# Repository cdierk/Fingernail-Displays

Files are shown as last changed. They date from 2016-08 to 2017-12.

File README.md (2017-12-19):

# Fingernail-Displays

## Hardware notes
The pink board is a [Teensy 3.2](https://www.pjrc.com/teensy/index.html). Here's the [pinout.](https://www.pjrc.com/teensy/pinout.html)

The tiny red epaper breakout board is from [this hackaday project.](https://hackaday.io/project/13327-teensy-e-paper-adapter-board).

## Software notes
The [code for the red e-paper breakout board is here,](https://github.com/jarek319/EPD215). Note that it was designed w/ an older pin layout, so you need to swap two of the pins as per [this issue on github.](https://github.com/jarek319/EPD215/issues/4).
Specifically, 

### Annotations
Difference between SPI and SWSPI is d1 and d0 are set to output in SWSPI.

Power on the cog driver:
```
initScreen()
...
  digitalWrite( _rs, HIGH );        //RES# = 1    <-----
  delay( 1 );                       //Delay 1ms          \
  digitalWrite( _cs, HIGH );        //CS# = 1      <---- these two lines power on the cog driver.

  Serial.println( "Waiting for busy signal" );
  while ( digitalRead( _bs ) == HIGH ); //Make sure BUSY = LOW      <---- first step of initializing COG driver.
```
[source](https://github.com/jarek319/EPD215/blob/e8205ba3651f23074bca707f821be8e2f3143674/EPD215.cpp#L281)
[download datasheet, pg. 10 of datasheet](http://www.pervasivedisplays.com/LiteratureRetrieve.aspx?ID=232068)

#### Testing
pin setup (SPI)
EPD215(17, 16, 14, 15)
Output: https://www.dropbox.com/s/jrkega85on69x7t/Screenshot%202017-12-15%2012.04.25.png?dl=0

EPD215(17, 16, 15, 14)

## Code to upload bitmap images

0. If you're using [this adapter board and a Teensy, as here,](https://hackaday.io/project/13327-teensy-e-paper-adapter-board) follow these steps.
1. Download [EPD215 library from here.](https://github.com/jarek319/EPD215). Those instructions will also have you install the [Adafruit GFX library.](https://github.com/adafruit/Adafruit-GFX-Library)
2.

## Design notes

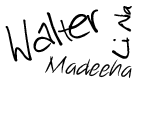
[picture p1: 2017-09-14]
Eink Designs/signatures3_1_9.png

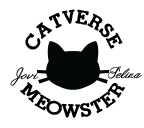
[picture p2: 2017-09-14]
Eink Designs/catverse_1_9.png

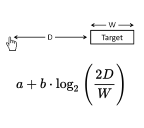
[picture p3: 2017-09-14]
Eink Designs/fitts_1_9.png

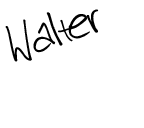
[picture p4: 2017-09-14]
Eink Designs/signatures1_1_9.png

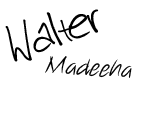
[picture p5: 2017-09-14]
Eink Designs/signatures2_1_9.png

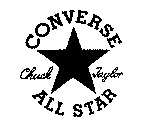
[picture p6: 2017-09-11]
Eink Designs/converse_1_9.jpg

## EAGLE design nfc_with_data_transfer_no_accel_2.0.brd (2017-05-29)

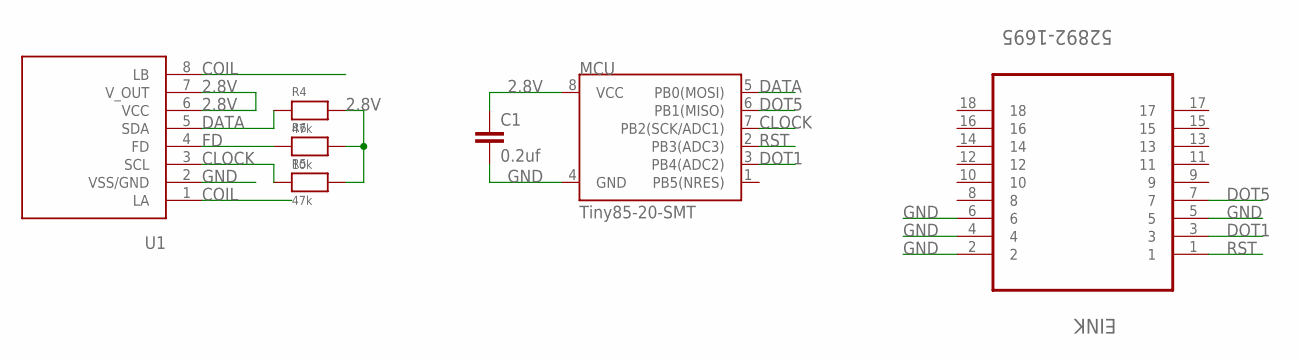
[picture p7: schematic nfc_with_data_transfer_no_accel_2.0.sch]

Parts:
C1: 0.2uf; 1206
EINK: 52892-1695; MOLEX_52892-1695
MCU: Tiny85-20-SMT; SO08-EIAJ
R4, R5: 47k; 0603
R6: 10k; 0603
U1: NT3H1101

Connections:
2.8V: C1.1, MCU.8 (VCC), R4.2, R5.2, R6.2, U1.6 (VCC), U1.7 (V_OUT)
CLOCK: MCU.7 (PB2(SCK/ADC1)), R5.1, U1.3 (SCL)
COIL: U1.1 (LA), U1.8 (LB)
DATA: MCU.5 (PB0(MOSI)), R4.1, U1.5 (SDA)
DOT1: EINK.3, MCU.3 (PB4(ADC2))
DOT5: EINK.7, MCU.6 (PB1(MISO))
FD: R6.1, U1.4 (FD)
GND: C1.2, EINK.2, EINK.4, EINK.5, EINK.6, MCU.4 (GND), U1.2 (VSS/GND)
RST: EINK.1, MCU.2 (PB3(ADC3))

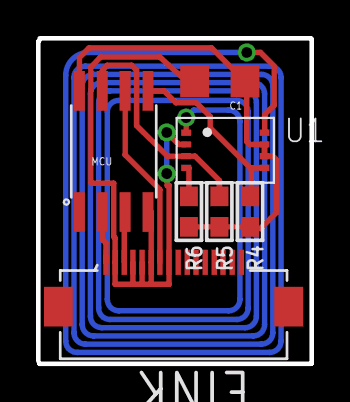
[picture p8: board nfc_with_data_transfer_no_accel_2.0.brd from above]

Board: 2 copper layers, 15.2 x 18.1 mm, 7 parts (0 on the bottom side), 9 nets.

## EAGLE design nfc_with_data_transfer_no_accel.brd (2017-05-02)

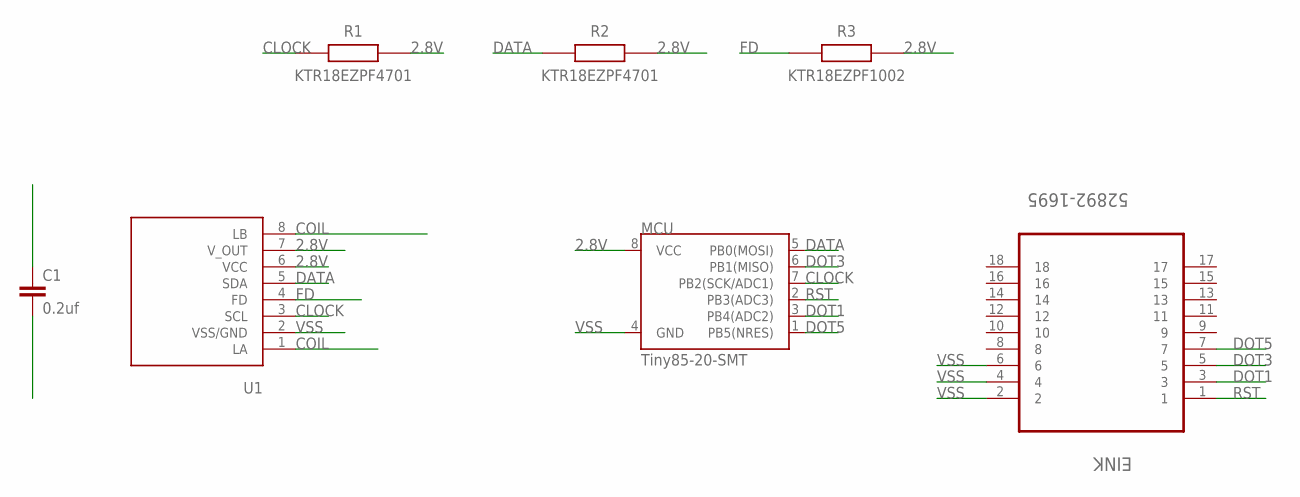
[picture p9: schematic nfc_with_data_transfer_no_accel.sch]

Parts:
C1: 0.2uf; 1206
EINK: 52892-1695; MOLEX_52892-1695
MCU: Tiny85-20-SMT; SO08-EIAJ
R1, R2: KTR18EZPF4701; RESC3216X65N
R3: KTR18EZPF1002; RESC3216X65N
U1: NT3H1101

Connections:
2.8V: C1.1, MCU.8 (VCC), R1.2, R2.2, R3.2, U1.6 (VCC), U1.7 (V_OUT)
CLOCK: MCU.7 (PB2(SCK/ADC1)), R1.1, U1.3 (SCL)
COIL: U1.1 (LA), U1.8 (LB)
DATA: MCU.5 (PB0(MOSI)), R2.1, U1.5 (SDA)
DOT1: EINK.3, MCU.3 (PB4(ADC2))
DOT3: EINK.5, MCU.6 (PB1(MISO))
DOT5: EINK.7
FD: R3.1, U1.4 (FD)
RST: EINK.1, MCU.2 (PB3(ADC3))
VSS: C1.2, EINK.2, EINK.4, EINK.6, MCU.4 (GND), U1.2 (VSS/GND)

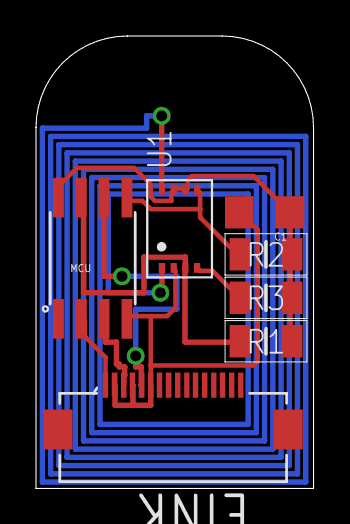
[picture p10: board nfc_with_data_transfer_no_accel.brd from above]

Board: 2 copper layers, 15.4 x 25.1 mm, 7 parts (0 on the bottom side), 9 nets.

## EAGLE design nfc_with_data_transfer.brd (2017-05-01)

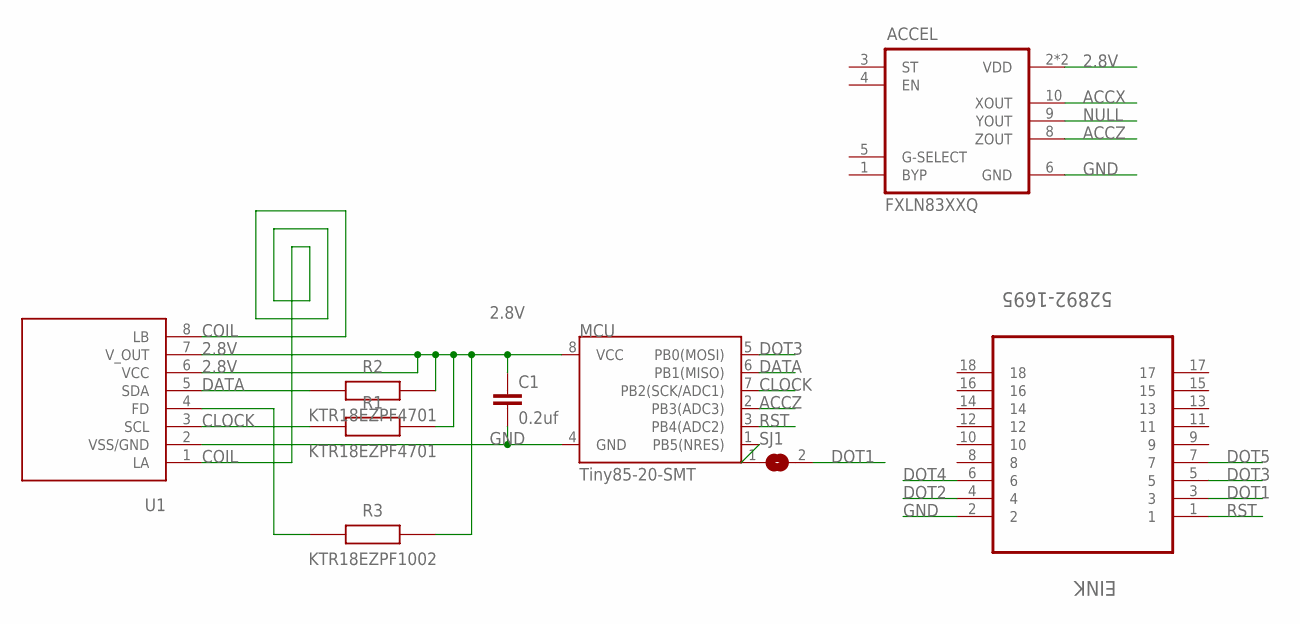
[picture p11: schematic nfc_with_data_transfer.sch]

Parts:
ACCEL: FXLN83XXQ; QFN12-3X3
C1: 0.2uf; 1206
EINK: 52892-1695; MOLEX_52892-1695
MCU: Tiny85-20-SMT; SO08-EIAJ
R1, R2: KTR18EZPF4701; RESC3216X65N
R3: KTR18EZPF1002; RESC3216X65N
SJ1: SOLDERJUMPER; SOLDERJUMPER_ARROW_NOPASTE
U1: NT3H1101

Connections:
2.8V: ACCEL.2 (VDD), ACCEL.7 (VDD), C1.1, MCU.8 (VCC), R1.2, R2.2, R3.2, U1.6 (VCC), U1.7 (V_OUT)
ACCX: ACCEL.10 (XOUT)
ACCZ: ACCEL.8 (ZOUT), MCU.2 (PB3(ADC3))
CLOCK: MCU.7 (PB2(SCK/ADC1)), U1.3 (SCL)
COIL: U1.1 (LA), U1.8 (LB)
DATA: MCU.6 (PB1(MISO)), U1.5 (SDA)
DOT1: EINK.3, SJ1.2
DOT2: EINK.4
DOT3: EINK.5, MCU.5 (PB0(MOSI))
DOT4: EINK.6
DOT5: EINK.7
GND: ACCEL.6 (GND), C1.2, EINK.2, MCU.4 (GND), U1.2 (VSS/GND)
unnamed: MCU.1 (PB5(NRES)), SJ1.1
unnamed: R3.1, U1.4 (FD)
NULL: ACCEL.9 (YOUT)
RST: EINK.1, MCU.3 (PB4(ADC2))

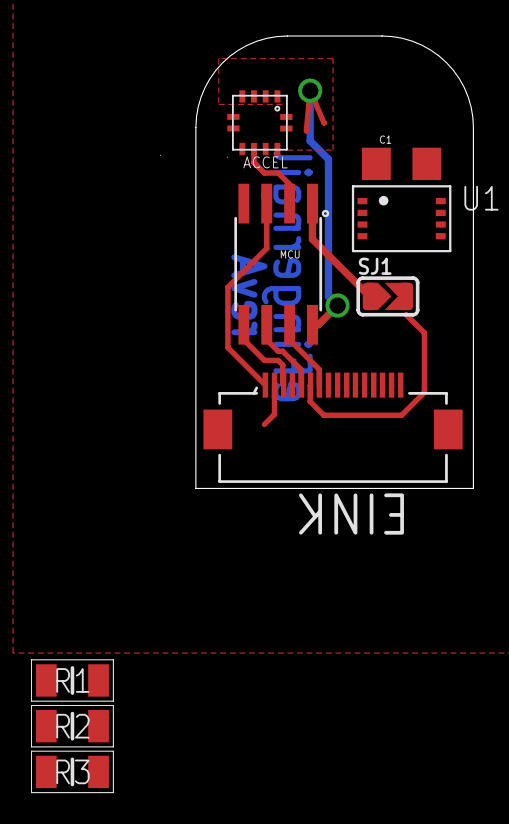
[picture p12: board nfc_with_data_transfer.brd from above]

Board: 2 copper layers, 15.4 x 25.1 mm, 9 parts (0 on the bottom side), 11 nets.

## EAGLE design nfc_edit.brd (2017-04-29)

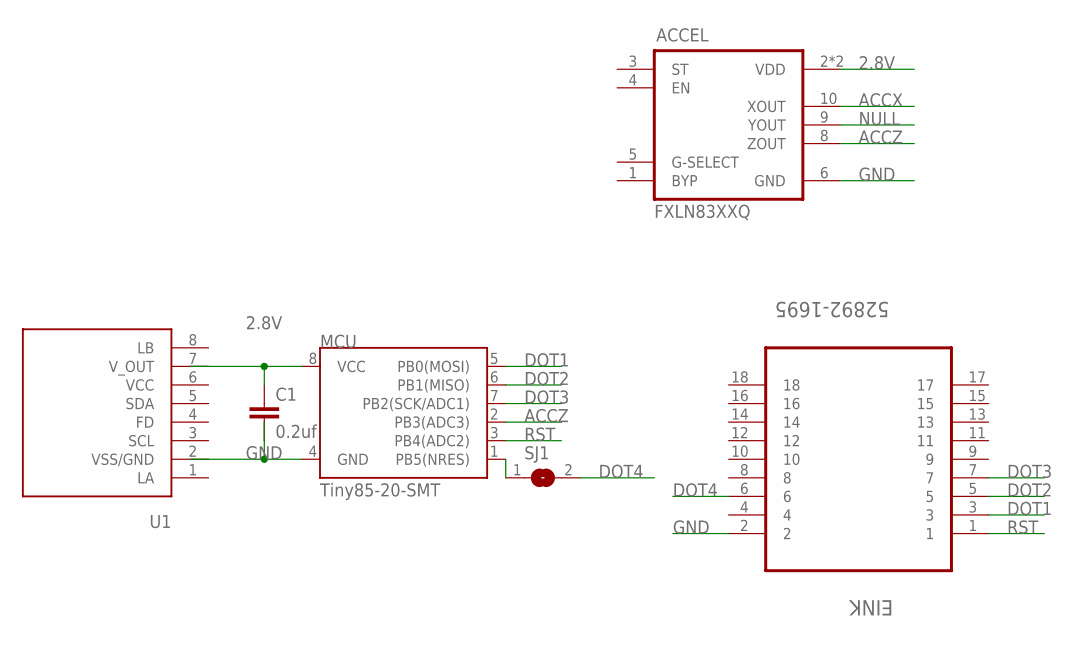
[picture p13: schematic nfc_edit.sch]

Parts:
ACCEL: FXLN83XXQ; QFN12-3X3
C1: 0.2uf; 1206
EINK: 52892-1695; MOLEX_52892-1695
MCU: Tiny85-20-SMT; SO08-EIAJ
SJ1: SOLDERJUMPER; SOLDERJUMPER_ARROW_NOPASTE
U1: NT3H1101

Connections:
2.8V: ACCEL.2 (VDD), ACCEL.7 (VDD), C1.1, MCU.8 (VCC), U1.7 (V_OUT)
ACCX: ACCEL.10 (XOUT)
ACCZ: ACCEL.8 (ZOUT), MCU.2 (PB3(ADC3))
DOT1: EINK.3, MCU.5 (PB0(MOSI))
DOT2: EINK.5, MCU.6 (PB1(MISO))
DOT3: EINK.7, MCU.7 (PB2(SCK/ADC1))
DOT4: EINK.6, SJ1.2
GND: ACCEL.6 (GND), EINK.2, MCU.4 (GND)
unnamed: MCU.1 (PB5(NRES)), SJ1.1
NULL: ACCEL.9 (YOUT)
RST: EINK.1, MCU.3 (PB4(ADC2))
VCC: U1.6 (VCC)
VSS/GND: U1.2 (VSS/GND)

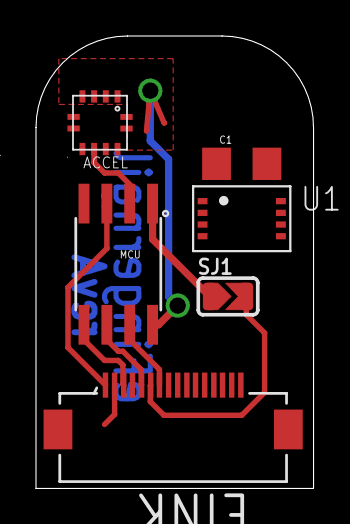
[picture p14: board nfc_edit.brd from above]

Board: 2 copper layers, 15.4 x 25.1 mm, 6 parts (0 on the bottom side), 9 nets.

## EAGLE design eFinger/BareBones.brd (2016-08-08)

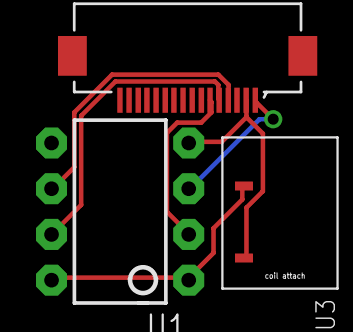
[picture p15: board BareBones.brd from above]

Board: 2 copper layers, 3 parts (0 on the bottom side), 7 nets.

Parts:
U1: TINY85-20-DIP; DIP08
U2: 52892-1695; MOLEX_52892-1695
U3: P9027LP-R

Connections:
unnamed: U1.3, U2.1
unnamed: U1.2, U2.6
unnamed: U1.1, U1.8, U3.OUT
unnamed: U1.4, U2.2, U3.P$2
unnamed: U1.5, U2.3
unnamed: U1.6, U2.4
unnamed: U1.7, U2.5

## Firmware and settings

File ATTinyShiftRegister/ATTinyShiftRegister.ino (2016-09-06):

/*
 * Christie Dierk
 * July 29, 2016
 * 
 */


#include <EEPROM.h>

// Clear pin is connected directly to ATTiny
// Connecting it to the Shift Register would free up a pin for the accelerometer
#define CLEAR_PIN 1
// currently only using the x value from the accelerometer
#define ACC_Z_PIN 3
#define REFRESH_DELAY 500 // min 250

//Pin connected to clock pin (SH_CP) of 74HC595
const int clockPin = 2; // pin 11 of 74HC595
////Pin connected to Data in (DS) of 74HC595
const int dataPin = 0; // pin 14 of 74HC595

int fullCount = 0;

//holders for infromation you're going to pass to shifting function
byte data;

void clearDisplay()
{

  digitalWrite(CLEAR_PIN, HIGH);
  // wait min settling time for 5V = 1200ms

  delay(REFRESH_DELAY);
  digitalWrite(CLEAR_PIN, LOW);

}

void setup() {
  //set pin to output because they are addressed in the main loop
  pinMode(CLEAR_PIN, OUTPUT);
  
  clearDisplay();
  
  fullCount = EEPROM.read(0);

  //Necessary
  shiftOut(dataPin, clockPin, 0);
  shiftOut(dataPin, clockPin, 0);
  delay(500);
}

void loop() {
 //only count up if accelerometer is tilted
 int firstZ = analogRead(ACC_Z_PIN);
 int secondZ = analogRead(ACC_Z_PIN);
 if (abs(firstZ - secondZ) > 2) {
    fullCount++;
  
    if (fullCount > 31){
      fullCount = 0;
    }
    data = (0xff & fullCount);
    EEPROM.write(0, (byte) data);

    shiftOut(dataPin, clockPin, MSBFIRST, fullCount);

    clearDisplay();
    delay(REFRESH_DELAY);
 }
}



// the heart of the program
// Method written by Carlyn Maw, Tom Igoe
// https://www.arduino.cc/en/Tutorial/ShftOut21
void shiftOut(int myDataPin, int myClockPin, byte myDataOut) {
  // This shifts 8 bits out MSB first, 
  //on the rising edge of the clock,
  //clock idles low

  //internal function setup
  int i=0;
  int pinState;
  pinMode(myClockPin, OUTPUT);
  pinMode(myDataPin, OUTPUT);

  //clear everything out just in case to
  //prepare shift register for bit shifting
  digitalWrite(myDataPin, 0);
  digitalWrite(myClockPin, 0);

  //for each bit in the byte myDataOut�
  //NOTICE THAT WE ARE COUNTING DOWN in our for loop
  //This means that %00000001 or "1" will go through such
  //that it will be pin Q0 that lights. 
  for (i=7; i>=0; i--)  {
    digitalWrite(myClockPin, 0);

    //if the value passed to myDataOut and a bitmask result 
    // true then... so if we are at i=6 and our value is
    // %11010100 it would the code compares it to %01000000 
    // and proceeds to set pinState to 1.
    if ( myDataOut & (1<<i) ) {
      pinState= 1;
    }
    else {  
      pinState= 0;
    }

    //Sets the pin to HIGH or LOW depending on pinState
    digitalWrite(myDataPin, pinState);
    //register shifts bits on upstroke of clock pin  
    digitalWrite(myClockPin, 1);
    //zero the data pin after shift to prevent bleed through
    digitalWrite(myDataPin, 0);
  }

  //stop shifting
  digitalWrite(myClockPin, 0);
}

//blinks the whole register based on the number of times you want to 
//blink "n" and the pause between them "d"
//starts with a moment of darkness to make sure the first blink
//has its full visual effect.
void blinkAll_2Bytes(int n, int d) {
  shiftOut(dataPin, clockPin, 0);
  shiftOut(dataPin, clockPin, 0);
  delay(200);
  for (int x = 0; x < n; x++) {
    shiftOut(dataPin, clockPin, 255);
    shiftOut(dataPin, clockPin, 255);
    delay(d);
    shiftOut(dataPin, clockPin, 0);
    shiftOut(dataPin, clockPin, 0);
    delay(d);
  }
}

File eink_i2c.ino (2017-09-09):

/*
 * Christine Dierk
 * September 9, 2017
 * 
 * Arduino code for dynamic wearable displays
 * Reads a value from i2c and then sets the connected eink display to the corresponding image
 */


#if defined(ENERGIA)
#include <Energia.h>
#else
#include <Arduino.h>
#endif

#include <inttypes.h>
#include <ctype.h>

// required libraries
#include <SPI.h>
#include <EPD_FLASH.h>
#include <EPD_V231_G2.h>
#define SCREEN_SIZE 190
#include <EPD_PANELS.h>
#include <S5813A.h>
#include <EPD_PINOUT.h>

//i2c library
#include <Wire.h>

// EEPROM
#include <EEPROM.h>

// select two images from:  text_image text-hello cat aphrodite venus saturn
#define IMAGE_1  converse
#define IMAGE_2  cat

//i2c
#define SLAVE_ADDR 0x55
#define int_reg_addr 0x01      //first block of user memory

// Error message for MSP430
#if (SCREEN_SIZE == 270) && defined(__MSP430G2553__)
#error MSP430: not enough memory
#endif

// no futher changed below this point

// current version number
#define DEMO_VERSION "5"


// pre-processor convert to string
#define MAKE_STRING1(X) #X
#define MAKE_STRING(X) MAKE_STRING1(X)

// other pre-processor magic
// token joining and computing the string for #include
#define ID(X) X
#define MAKE_NAME1(X,Y) ID(X##Y)
#define MAKE_NAME(X,Y) MAKE_NAME1(X,Y)
#define MAKE_JOIN(X,Y) MAKE_STRING(MAKE_NAME(X,Y))

// calculate the include name and variable names
#define IMAGE_1_FILE MAKE_JOIN(IMAGE_1,EPD_IMAGE_FILE_SUFFIX)
#define IMAGE_1_BITS MAKE_NAME(IMAGE_1,EPD_IMAGE_NAME_SUFFIX)
#define IMAGE_2_FILE MAKE_JOIN(IMAGE_2,EPD_IMAGE_FILE_SUFFIX)
#define IMAGE_2_BITS MAKE_NAME(IMAGE_2,EPD_IMAGE_NAME_SUFFIX)


// Add Images library to compiler path
#include <Images.h>  // this is just an empty file

// images
PROGMEM const
#define unsigned
#define char uint8_t
#include IMAGE_1_FILE
#undef char
#undef unsigned

PROGMEM const
#define unsigned
#define char uint8_t
#include IMAGE_2_FILE
#undef char
#undef unsigned



// LED anode through resistor to I/O pin
// LED cathode to Ground
#define LED_ON  HIGH
#define LED_OFF LOW


// define the E-Ink display
EPD_Class EPD(EPD_SIZE,
        Pin_PANEL_ON,
        Pin_BORDER,
        Pin_DISCHARGE,
#if EPD_PWM_REQUIRED
        Pin_PWM,
#endif
        Pin_RESET,
        Pin_BUSY,
        Pin_EPD_CS);


//i2c
byte rdata_1;
byte rdata_2;
byte rdata_3;
byte rdata_4;
byte rdata_5;
byte rdata_6;
byte rdata_7;
byte rdata_8;
byte rdata_9;
byte rdata_11;
byte rdata_12;
byte rdata_13;
byte rdata_14;
byte rdata_15;
byte rdata_16;

//EEPROM
int eeprom_addr = 0;
int current_state; 

// I/O setup
void setup() {
  Wire.begin();                         // join i2c bus 
  pinMode(Pin_RED_LED, OUTPUT);
  pinMode(Pin_SW2, INPUT);
  pinMode(Pin_TEMPERATURE, INPUT);
#if EPD_PWM_REQUIRED
  pinMode(Pin_PWM, OUTPUT);
#endif
  pinMode(Pin_BUSY, INPUT);
  pinMode(Pin_RESET, OUTPUT);
  pinMode(Pin_PANEL_ON, OUTPUT);
  pinMode(Pin_DISCHARGE, OUTPUT);
  pinMode(Pin_BORDER, OUTPUT);
  pinMode(Pin_EPD_CS, OUTPUT);
  pinMode(Pin_EPD_FLASH_CS, OUTPUT);

  digitalWrite(Pin_RED_LED, LOW);
#if EPD_PWM_REQUIRED
  digitalWrite(Pin_PWM, LOW);
#endif
  digitalWrite(Pin_RESET, LOW);
  digitalWrite(Pin_PANEL_ON, LOW);
  digitalWrite(Pin_DISCHARGE, LOW);
  digitalWrite(Pin_BORDER, LOW);
  digitalWrite(Pin_EPD_CS, LOW);
  digitalWrite(Pin_EPD_FLASH_CS, HIGH);

  Serial.begin(9600);
  delay(500);

#if defined(__AVR__)
  // // indefinite wait for USB CDC serial port to connect.  Arduino Leonardo only
  // while (!Serial) {
  // }
  // additional delay for USB CDC serial port to connect.  Arduino Leonardo only
  if (!Serial) {       // allows terminal time to sync as long
    delay(500);  // as the serial monitor is opened before
  }                    // upload
#endif

  Serial.println();
  Serial.println();
  Serial.println("Demo version: " DEMO_VERSION);
  Serial.println("Display size: " MAKE_STRING(EPD_SIZE));
  Serial.println("Film: V" MAKE_STRING(EPD_FILM_VERSION));
  Serial.println("COG: G" MAKE_STRING(EPD_CHIP_VERSION));
  Serial.println();

  Serial.println("Image 1: " IMAGE_1_FILE);
  Serial.println("Image 2: " IMAGE_2_FILE);
  Serial.println();

  EPD_FLASH.begin(Pin_EPD_FLASH_CS);
  if (EPD_FLASH.available()) {
    Serial.println("EPD FLASH chip detected OK");
  } else {
    uint8_t maufacturer;
    uint16_t device;
    EPD_FLASH.info(&maufacturer, &device);
    Serial.print("unsupported EPD FLASH chip: MFG: 0x");
    Serial.print(maufacturer, HEX);
    Serial.print("  device: 0x");
    Serial.print(device, HEX);
    Serial.println();
  }

  // configure temperature sensor
  S5813A.begin(Pin_TEMPERATURE);

  current_state = 0;
  current_state = EEPROM.read(eeprom_addr);
}

static int state = 0;
byte desired_state;
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

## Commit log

2016-08-08 First Commit: ATTiny + Shift Register + Eink + Accelerometer
    Accelerometer code not quite working
2016-08-08 Adding Eagle files
    These Eagle files contain ATTiny, IDT Receiver circuit (rough placement
    of pads), and FPC connector only.
    [BareBones.brd, BareBones.sch]
2016-08-08 Added Shift Register to Eagle schematic
    Haven’t drawn connections from Shift Register to FPC, but should be
    straight forward. Also haven’t added Accelerometer, not sure which one
    to use—need to order
    [ShiftReg+Accel.sch]
2016-08-15 Accelerometer code working
    Binary count only when accelerometer is tilted in the -x direction
2016-09-06 Accelerometer and connections added to Eagle file
    [eFingernailAllComponents.sch]
2016-09-06 Eagle part library for IDT Power Receiver
2016-09-14 AlterNail Code: Pick a Design
    Code with updated pin connections (to match circuitry). Alternates
    between 1 dot and 3 dots depending on vibration (uses simple
    thresholding)
    [Alternail_pick_a_design.ino]
2016-11-08 latest board
    [SOICtoDIPAdapter.brd, SOICtoDIPAdapter.sch, eFingernailAllComponents.brd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]
2017-04-29 Replaced Wireless Power Kit with NFC chip
    Updated schematic and board with NT3H1101 nfc chip in place of IDT wireless reference kit. AlterNail.lbr includes a custom package for this part (NT3H1101). The datasheet for NT3H1101 recommends placing a capacitor between vout and gnd; however, this schematic does not include this component (...yet).
    [nfc_edit.brd, nfc_edit.sch]
2017-04-29 .2uF capacitor has been added
    NFC added and connected via power only (no data transfer with ATTiny85)
    [nfc_edit.brd, nfc_edit.sch]
2017-04-29 give up 2 pins on ATTiny for I2C
    connected nfc chip (with .2uf capacitor). gave up 2 pins on ATTiny for I2C. Still control middle dot and potentially top dot with reset pin.
    [nfc_with_data_transfer.brd, nfc_with_data_transfer.sch]
2017-05-01 Added suggested resistors
    Added 4k7 pull-up resistors on SCL and SDA pins. Also added 10 kOhm pull-up resistor on Field Detection line.
    [nfc_with_data_transfer.brd, nfc_with_data_transfer.sch]
2017-05-01 Library files for added resistors
2017-05-02 Updated ATTiny85 pin connections, removed accel
    updated pin connections for I2C (data & clock), removed the accelerometer
    [nfc_with_data_transfer_no_accel.brd, nfc_with_data_transfer_no_accel.sch]
2017-05-02 Updated board (with traces and embedded coil)
    [nfc_with_data_transfer_no_accel.brd, nfc_with_data_transfer_no_accel.sch]
2017-05-04 fixed rst
    [nfc_with_data_transfer_no_accel_2.0.brd, nfc_with_data_transfer_no_accel_2.0.sch]
2017-05-23 latest without top ground plane
    [nfc_with_data_transfer_no_accel_2.0.brd]
2017-05-29 Tweaks by Eric to produce first manufactured board
    [nfc_with_data_transfer_no_accel_2.0.brd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]
2017-09-09 Latest fingernail code (i2c -> display)
    The most recent fingernail code in which the ATTiny85 reads block 0x01 of NT3H1101 user memory. The ATTiny85 then updates the e-ink display with the corresponding design. This code allows for seamles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
2017-09-09 Arduino code for dynamic wearable displays
    Reads a value from i2c and then sets the connected eink display to the corresponding image

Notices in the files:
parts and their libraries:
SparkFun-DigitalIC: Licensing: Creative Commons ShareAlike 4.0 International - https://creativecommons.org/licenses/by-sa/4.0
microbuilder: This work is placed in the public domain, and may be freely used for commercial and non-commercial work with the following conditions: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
